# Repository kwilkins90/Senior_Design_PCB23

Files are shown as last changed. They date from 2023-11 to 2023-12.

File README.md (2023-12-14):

The files attached to this repo reflect the final iteration of the Data Capture Module. The PCB's final revision if RevF and the final revision for the packaging of the device is revision G.
There are several errors found on the PCB in this current iteration:
- The footprint for the display jack has pins that are incorrectly ordered.
- D1's belly pad should not be grounded.
- The Raspberry Pi was not correctly mirrored to the back of the PCB.

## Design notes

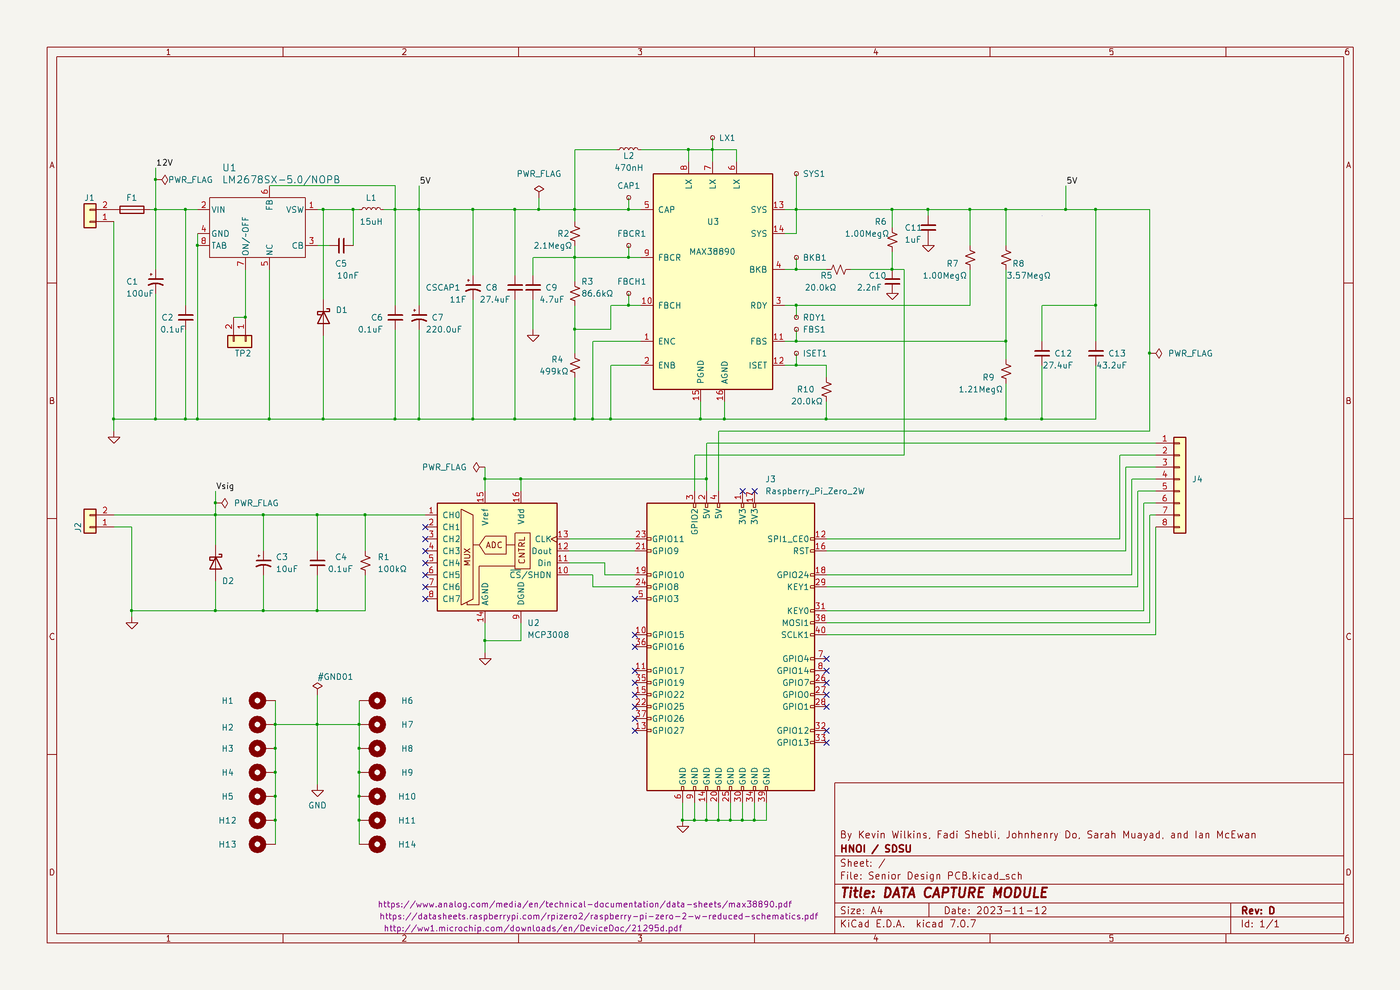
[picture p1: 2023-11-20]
SchematicRevD_KevinWilkins.png

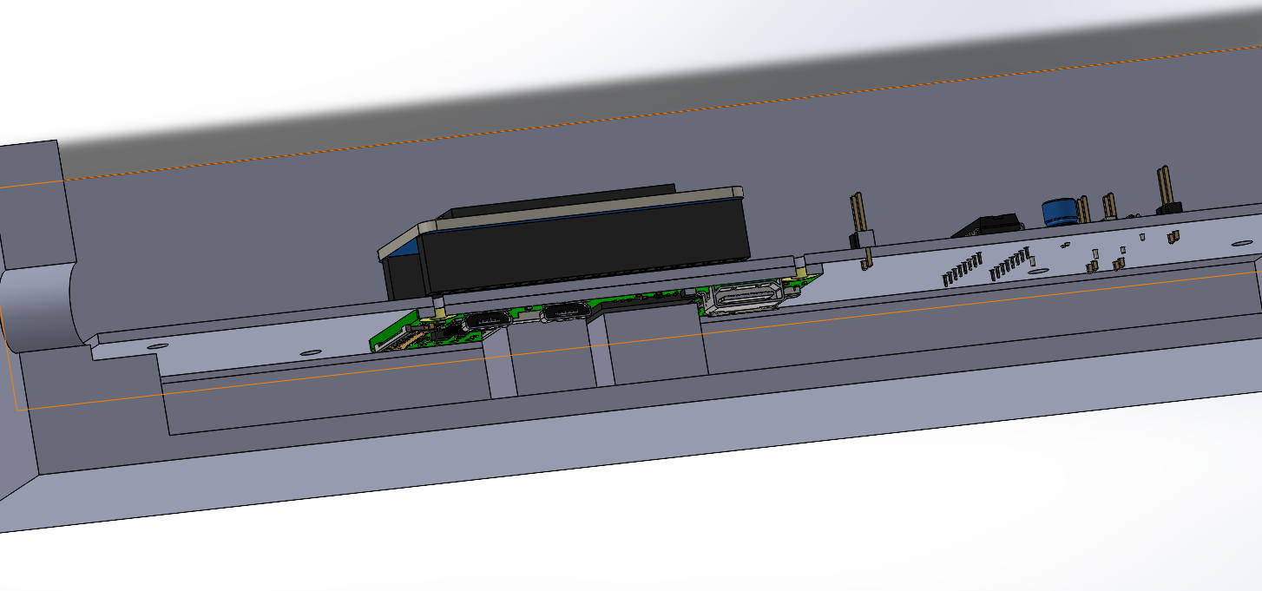
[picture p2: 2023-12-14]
SolidWorks Files/SWNOV18/screenshot1.png

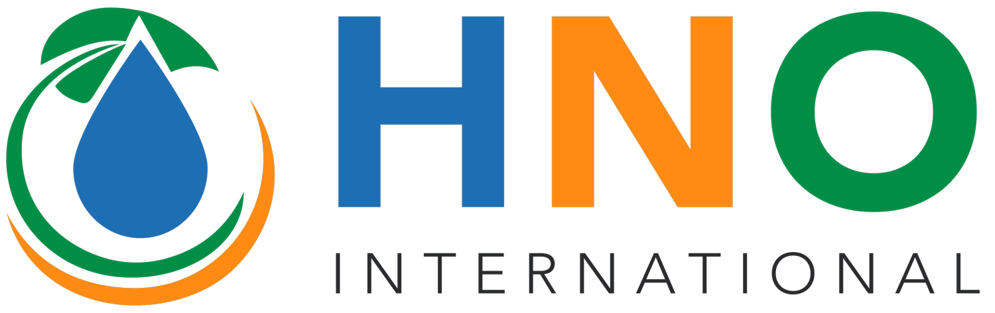
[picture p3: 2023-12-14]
SolidWorks Files/SWNOV18/HNOINTLCOLOR.png

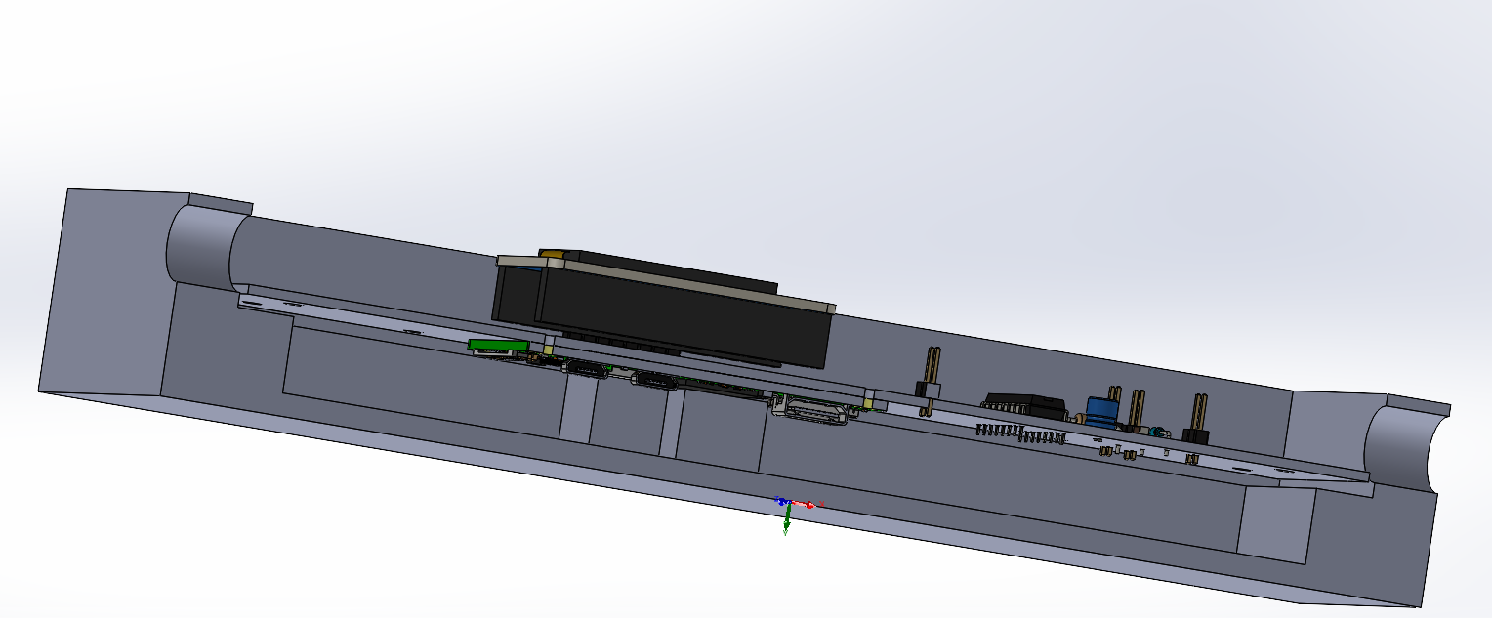
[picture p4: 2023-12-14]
SolidWorks Files/SWNOV18/screenshot2.png

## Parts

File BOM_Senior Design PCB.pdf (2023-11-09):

Source: | C:\Users\james\Desktop\College\SDSU year 3\492\Senior Design PCB\Senior Design PCB.kic
Date: | ########
Tool: | Eeschema 7.0.7
Generator: C:\Program Files\KiCad\7.0\bin\scripting\plugins/bom_csv_grouped_by_value_with_fp.py
Componen | 60
Ref | Qnty | Value | Cmp name Footprint DescriptionVendor | DNP
BKB1 | 1 TestPoint_STestPoint_STestPoint:Ttest point
C1 | 1 100uF | C_PolarizedCapacitor_TPolarized capacitor, small US symbol
C2, C6 | 2 0.1uF | C_Small Capacitor_TUnpolarized capacitor, small symbol
C3 | 1 10uF | C_PolarizedCapacitor_TPolarized capacitor, small US symbol
C4 | 1 0.1uF | C_Small Capacitor_SUnpolarized capacitor, small symbol
C5 | 1 10nF | C_Small Capacitor_TUnpolarized capacitor, small symbol
C7 | 1 220.0uF C_PolarizedCapacitor_SPolarized capacitor, small US symbol
C8, C12 | 2 27.4uF | C_Small AAA_senio Unpolarized capacitor, small symbol
C9 | 1 4.7uF | C_Small AAA_senio Unpolarized capacitor, small symbol
C10 | 1 2.2nF | C_Small AAA_senio Unpolarized capacitor, small symbol
C11 | 1 1uF | C_Small AAA_senio Unpolarized capacitor, small symbol
C13 | 1 43.2uF | C_Small AAA_senio Unpolarized capacitor, small symbol
CAP1 | 1 TestPoint_STestPoint_STestPoint:Ttest point
CSCAP1 | 1 11F | C_PolarizedCapacitor_TPolarized capacitor, small US symbol
D1 | | 1 40V | D_SchottkyAAA_senio Schottky diode
D2 | | 1 5.1V | D_SchottkyDiode_THT Schottky diode
ENB1 | 1 TestPoint_STestPoint_STestPoint:Ttest point
ENC1 | 1 TestPoint_STestPoint_STestPoint:Ttest point
F1, F2, F3, F | 4 Fuse | Fuse | AAA_senio Fuse
FBCH1 | 1 TestPoint_STestPoint_STestPoint:Ttest point
FBCR1 | 1 TestPoint_STestPoint_STestPoint:Ttest point
FBS1 | 1 TestPoint_STestPoint_STestPoint:Ttest point
H1, H2, H3, | 4 MountingHMountingHMountingHMounting Hole with connection
H5, H6, H7, | 4 MountingHMountingHMountingHMounting Hole with connection
ISET1 | 1 TestPoint_STestPoint_STestPoint:Ttest point
J1, J2 | 2 Conn_01x0Conn_01x0Connector_Generic connector, single row, 01x02, script g
J3 | 1 Raspberry_Raspberry_Module:Ra expansion header for Raspberry Pi Zero 2W
J7-1, J7-2 | 2 Conn_01x0Conn_01x0Connector_Generic connector, single row, 01x04, script g
L1 | | 1 15uH | L_Small AAA_senio Inductor, small symbol
L2 | | 1 470nH | L_Small AAA_senio Inductor, small symbol
LX1 | 1 TestPoint_STestPoint_STestPoint:Ttest point
R1 | 1 100kÎ© R_Small_USResistor_THResistor, small US symbol
R2 | 1 2.1MegÎ© R_Small_USAAA_senio Resistor, small US symbol
R3 | 1 86.6kÎ© R_Small_USAAA_senio Resistor, small US symbol
R4 | 1 499kÎ© R_Small_USAAA_senio Resistor, small US symbol
R5, R10 | 2 20.0kÎ© R_Small_USAAA_senio Resistor, small US symbol
R6, R7 | 2 1.00MegÎ©R_Small_USAAA_senio Resistor, small US symbol
R8 | 1 3.57MegÎ©R_Small_USAAA_senio Resistor, small US symbol
R9 | 1 1.21MegÎ©R_Small_USAAA_senio Resistor, small US symbol
RDY1 | 1 TestPoint_STestPoint_STestPoint:Ttest point
SYS1 | 1 TestPoint_STestPoint_STestPoint:Ttest point

TP2 | 1 Conn_01x0Conn_01x0Connector_Generic connector, single row, 01x02, script g
U1 | 1 LM2678SX-LM2678SX-AAA_senior_design:TS7B
U2 | 1 MCP3008 MCP3008 Package_D A/D Converter, 10-Bit, 8-Channel, SPI Interface
U3 | 1 MAX38890 MAX38890 Package_D 2.5V to 5.5V, 5A Reversible Buck/Boost Reg fo

enerated (kicad-library-utils/schlib/autogen/connector/)

enerated (kicad-library-utils/schlib/autogen/connector/)

enerated (kicad-library-utils/schlib/autogen/connector/)

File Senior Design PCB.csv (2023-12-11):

Source: | C:\Users\james\Desktop\College\SDSU year 3\492\Senior Design PCB\Senior Design PCB.kicad_sch
Date: | 11/19/2023 5:33:28 PM
Tool: | Eeschema 7.0.7
Generator: | C:\Program Files\KiCad\7.0\bin\scripting\plugins/bom_csv_grouped_by_value_with_fp.py
Component Count: | 61
Ref | Qnty | Value | Cmp name | Footprint | Description | Vendor | DNP
BKB1 | 1 | TestPoint_Small | TestPoint_Small | TestPoint:TestPoint_Pad_D2.0mm | test point
C1 | 1 | 100uF | C_Polarized_Small_US | Capacitor_THT:CP_Radial_D8.0mm_P2.50mm | Polarized capacitor, small US symbol
C2, C6 | 2 | 0.1uF | C_Small | Capacitor_THT:CP_Radial_D5.0mm_P2.50mm | Unpolarized capacitor, small symbol
C3 | 1 | 10uF | C_Polarized_Small_US | Capacitor_THT:CP_Radial_D5.0mm_P2.00mm | Polarized capacitor, small US symbol
C4 | 1 | 0.1uF | C_Small | Capacitor_SMD:C_1206_3216Metric | Unpolarized capacitor, small symbol
C5 | 1 | 10nF | C_Small | Capacitor_THT:CP_Radial_D10.0mm_P3.80mm | Unpolarized capacitor, small symbol
C7 | 1 | 220.0uF | C_Polarized_Small_US | Capacitor_SMD:CP_Elec_8x6.9 | Polarized capacitor, small US symbol
C8, C12 | 2 | 27.4uF | C_Small | AAA_senior_design:CAPC3216X180N | Unpolarized capacitor, small symbol
C9 | 1 | 4.7uF | C_Small | AAA_senior_design:CAPC1608X87N | Unpolarized capacitor, small symbol
C10 | 1 | 2.2nF | C_Small | AAA_senior_design:0603 | Unpolarized capacitor, small symbol
C11 | 1 | 1uF | C_Small | AAA_senior_design:CAP_C0603_CND | Unpolarized capacitor, small symbol
C13 | 1 | 43.2uF | C_Small | AAA_senior_design:CAPC3225X270N | Unpolarized capacitor, small symbol
CAP1 | 1 | TestPoint_Small | TestPoint_Small | TestPoint:TestPoint_Pad_D2.0mm | test point
CSCAP1 | 1 | 11F | C_Polarized_Small_US | Capacitor_THT:CP_Radial_D10.0mm_P5.00mm | Polarized capacitor, small US symbol
D1 | 1 | 40V | D_Schottky | AAA_senior_design:D2PAK_STM | Schottky diode
D2 | 1 | 5.1V | D_Schottky | Diode_THT:D_DO-34_SOD68_P10.16mm_Horizontal | Schottky diode
FBCH1 | 1 | TestPoint_Small | TestPoint_Small | TestPoint:TestPoint_Pad_D2.0mm | test point
FBCR1 | 1 | TestPoint_Small | TestPoint_Small | TestPoint:TestPoint_Pad_D2.0mm | test point
FBS1 | 1 | TestPoint_Small | TestPoint_Small | TestPoint:TestPoint_Pad_D2.0mm | test point
H1, H2, H3, H4, H5, H6, H7, H8, H9, H10, H11, H12 | 12 | MountingHole_Pad | MountingHole_Pad | MountingHole:MountingHole_3.2mm_M3_DIN965_Pad | Mounting Hole with connection
ISET1 | 1 | TestPoint_Small | TestPoint_Small | TestPoint:TestPoint_Pad_D2.0mm | test point
J1, J2, J8, J9, J10, J11 | 6 | Conn_01x02 | Conn_01x02 | Connector_PinHeader_2.54mm:PinHeader_1x02_P2.54mm_Vertical | Generic connector, single row, 01x02, script generated (kicad-library-utils/schlib/autogen/connector/)
J3 | 1 | Raspberry_Pi_Zero_2W | Raspberry_Zero_2W | Module:Raspberry_Pi_Zero_Socketed_THT_FaceDown_MountingHoles | expansion header for Raspberry Pi Zero 2W
J4 | 1 | Conn_01x08 | Conn_01x08 | Connector_PinHeader_2.54mm:PinHeader_1x08_P2.54mm_Vertical | Generic connector, single row, 01x08, script generated (kicad-library-utils/schlib/autogen/connector/)
L1 | 1 | 15uH | L_Small | AAA_senior_design:15uHInductor | Inductor, small symbol
L2 | 1 | 470nH | L_Small | AAA_senior_design:INDC2520X120N | Inductor, small symbol
LX1 | 1 | TestPoint_Small | TestPoint_Small | TestPoint:TestPoint_Pad_D2.0mm | test point
R1 | 1 | 100kΩ | R_Small_US | Resistor_THT:R_Axial_DIN0207_L6.3mm_D2.5mm_P10.16mm_Horizontal | Resistor, small US symbol
R2 | 1 | 2.1MegΩ | R_Small_US | AAA_senior_design:RESC1508X50N | Resistor, small US symbol
R3 | 1 | 86.6kΩ | R_Small_US | AAA_senior_design:RES_ERJ3EKF4023V | Resistor, small US symbol
R4 | 1 | 499kΩ | R_Small_US | AAA_senior_design:RESC1508X50N | Resistor, small US symbol
R5, R10 | 2 | 20.0kΩ | R_Small_US | AAA_senior_design:RESC1508X50N | Resistor, small US symbol
R6, R7 | 2 | 1.00MegΩ | R_Small_US | AAA_senior_design:RESC1508X50N | Resistor, small US symbol
R8 | 1 | 3.57MegΩ | R_Small_US | AAA_senior_design:RESC1508X50N | Resistor, small US symbol
R9 | 1 | 1.21MegΩ | R_Small_US | AAA_senior_design:RESC1508X50N | Resistor, small US symbol
RDY1 | 1 | TestPoint_Small | TestPoint_Small | TestPoint:TestPoint_Pad_D2.0mm | test point
SYS1 | 1 | TestPoint_Small | TestPoint_Small | TestPoint:TestPoint_Pad_D2.0mm | test point
TP2 | 1 | Conn_01x02 | Conn_01x02 | Connector_PinHeader_2.54mm:PinHeader_1x02_P2.54mm_Vertical | Generic connector, single row, 01x02, script generated (kicad-library-utils/schlib/autogen/connector/)
U1 | 1 | LM2678SX-5.0/NOPB | LM2678SX-5.0_NOPB | AAA_senior_design:TS7B
U2 | 1 | MCP3008 | MCP3008 | Package_DIP:DIP-16_W7.62mm_LongPads | A/D Converter, 10-Bit, 8-Channel, SPI Interface , 2.7V-5.5V
U3 | 1 | MAX38890 | MAX38890 | Package_DFN_QFN:TQFN-16-1EP_3x3mm_P0.5mm_EP1.23x1.23mm | 2.5V to 5.5V, 5A Reversible Buck/Boost Reg for Backup Apps

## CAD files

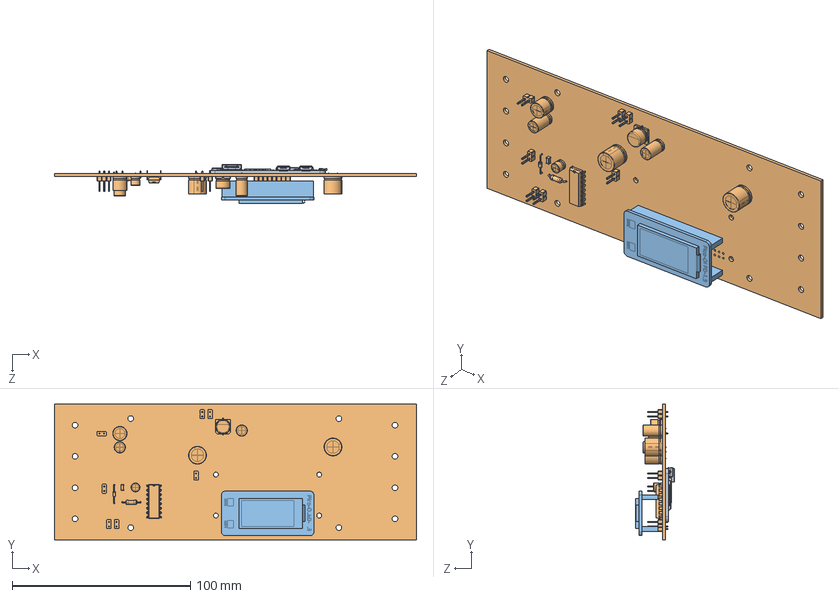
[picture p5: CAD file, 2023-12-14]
SolidWorks Files/SWNOV18/Assem2.SLDASM
203.2 x 76.2 x 22.0 mm
Raspberry Pi Zero 2 W
SeniorDesignPCB11182023
Pico-OLED-1.3.step

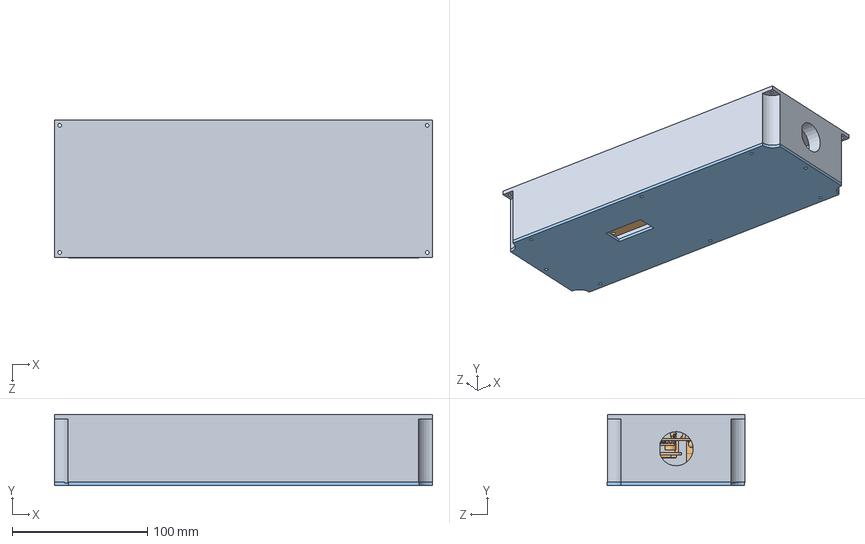
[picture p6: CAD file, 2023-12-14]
SolidWorks Files/SWNOV18/HNOIPackageASSy.SLDASM
279.5 x 52.7 x 101.7 mm
Pcb,display,rpi
Lid

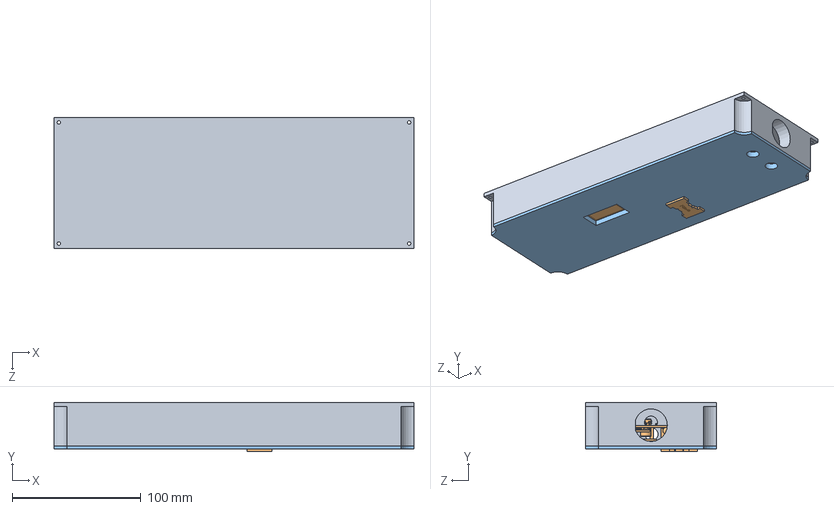
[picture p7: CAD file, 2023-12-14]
SolidWorks Files/SWNOV18/new assembly.SLDASM
279.4 x 38.2 x 101.6 mm
Pcb,display,rpi
Lid

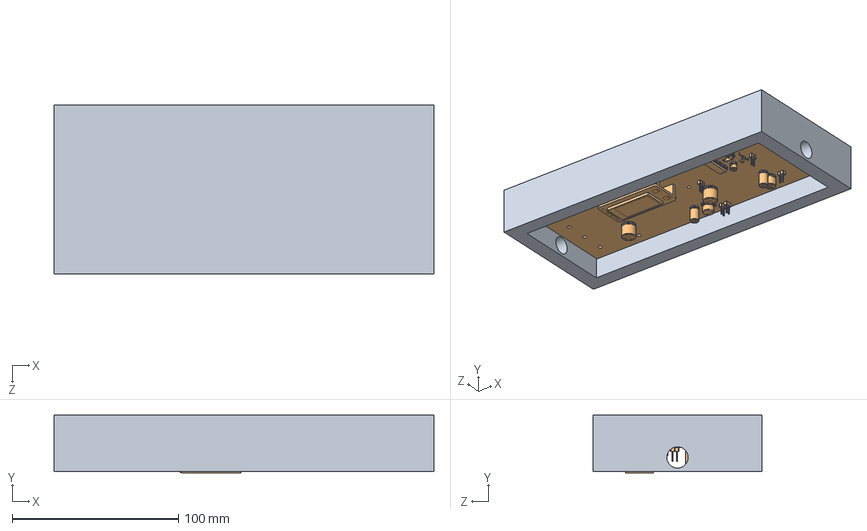
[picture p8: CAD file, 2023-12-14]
SolidWorks Files/SWNOV18/Assem3.SLDASM
228.6 x 34.7 x 101.6 mm
Assem2 part

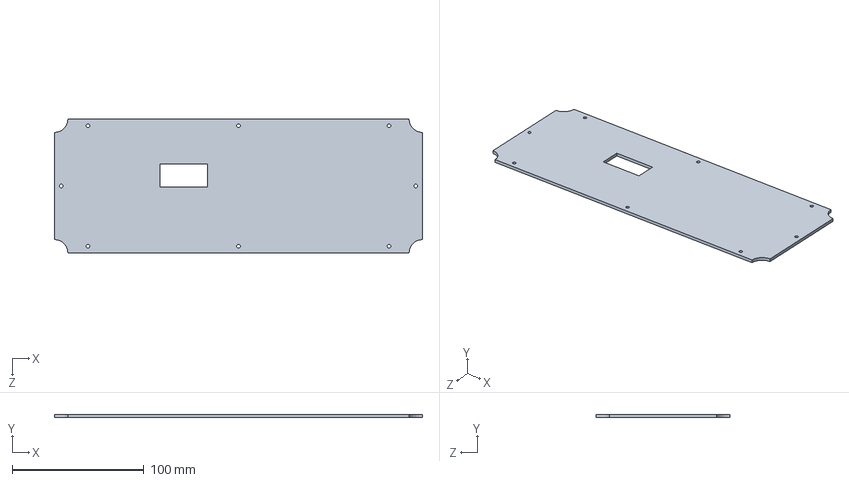
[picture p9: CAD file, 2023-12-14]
SolidWorks Files/SWNOV18/Lid.SLDPRT
279.4 x 2.54 x 101.6 mm

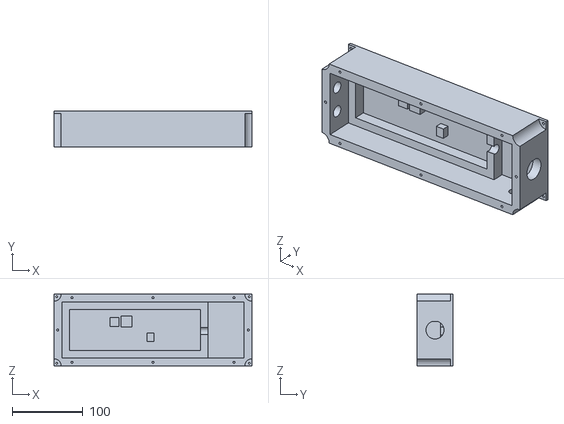
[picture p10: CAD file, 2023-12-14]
SolidWorks Files/SWNOV18/box13dprintver.STL
279.4 x 50.8 x 101.6

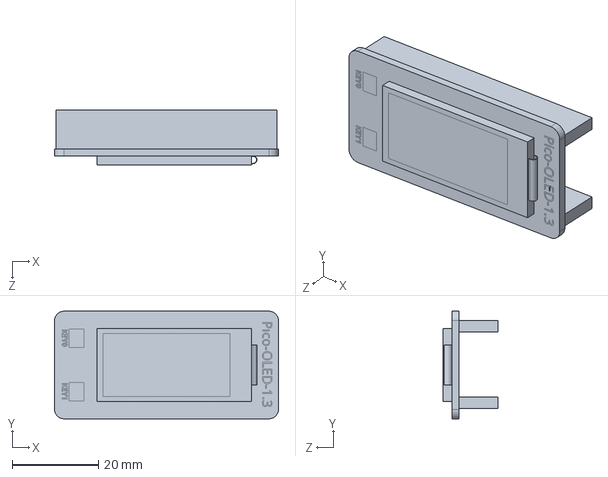
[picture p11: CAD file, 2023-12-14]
SolidWorks Files/SWNOV18/Pico-OLED-1.3.step.SLDPRT
52.0 x 25.0 x 12.7 mm

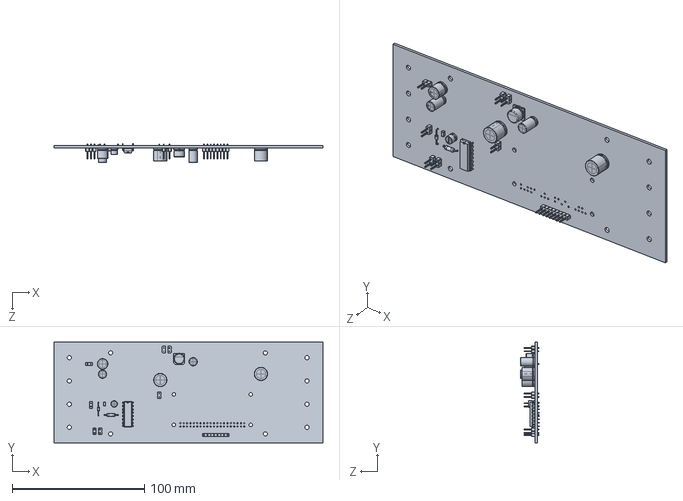
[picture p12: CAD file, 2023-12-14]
SolidWorks Files/SWNOV18/SeniorDesignPCB11182023.SLDPRT
203.2 x 76.2 x 14.3 mm

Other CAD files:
SolidWorks Files/SWNOV18/box1.SLDPRT
SolidWorks Files/SWNOV18/Lid3dprinter.STL

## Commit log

2023-11-05 More footprints added.
    [Senior Design PCB.kicad_sch]
2023-11-09 All footprints added.
    [BOM_Senior Design PCB.csv, Senior Design PCB.csv, Senior Design PCB.kicad_sch]
2023-11-09 Fixed a few footprints. Started the design process. I'll start making branches after today.
    [Senior Design PCB.csv, Senior Design PCB.kicad_pcb, Senior Design PCB.kicad_sch]
2023-11-11 Laid second draft of traces. No ground plane has been added.
    [Senior Design PCB.kicad_pcb]
2023-11-12 Laid fourth draft of traces and passed all drc checks. gnd planes added and the mounting holes are added, as well. Remaining steps are to add leds or 50k ohm resistor.
    [Senior Design PCB.kicad_pcb, Senior Design PCB.kicad_sch]
2023-11-20 Mark Bruno edits implemented.
    [BOM_Senior Design PCB.csv, Senior Design PCB.csv, Senior Design PCB.kicad_pcb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]
2023-12-11 Final files added to 'most recent files' branch.
    [Senior Design PCB.csv, Senior Design PCB.kicad_pcb]
2023-12-14 Final files added and SolidWorks files.
    [Assem2.SLDASM, Assem3.SLDASM, HNOIPackageASSy.SLDASM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]
